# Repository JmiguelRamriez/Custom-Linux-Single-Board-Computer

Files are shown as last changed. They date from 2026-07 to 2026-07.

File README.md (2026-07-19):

# Custom Linux Single Board Computer

Open-source hardware design for a minimal **Allwinner V3s**-based Single Board Computer, designed with **KiCad 9.0**.

## Features

- **Allwinner V3s** — ARM Cortex-A7 @ 1.2 GHz with **64 MB integrated DDR2 RAM** (SiP)
- **EA3036CQB** PMIC — 3-channel regulator (1.2V / 1.8V / 3.3V) from 5V input
- **10/100 Ethernet** — integrated PHY in V3s + RJ45 with magnetics (Hanrun HR911105A)
- **USB Type-C** — power input (5V) and USB OTG
- **USB Type-A** — host port
- **microSD** card slot (Molex 104031-0811, push-push) — boot and storage
- **Debug UART** — 3-pin 2.54mm header for serial console
- **GPIO header** — 2x20 pin, Raspberry Pi-like pinout
- **CR1220** coin cell holder — RTC backup
- **Boot/reset button**

## Pinout (J6 — 40-pin GPIO Header)

```
         +3.3V  (1)  (2)  +5V
     UART2_TX  (3)  (4)  +5V
     UART2_RX  (5)  (6)  GND
     I2C0_SCL  (7)  (8)  PWM0
     I2C0_SDA  (9) (10)  PWM1
    SPI0_MISO (11) (12)  GPIO_PE2
     SPI0_CLK (13) (14)  GND
      SPI0_CS (15) (16)  GPIO_PE4
    SPI0_MOSI (17) (18)  GPIO_PE6
    GPIO_PE0  (19) (20)  GND
         +3.3V (21) (22) GPIO_PE8
    GPIO_PE1  (23) (24)  GPIO_PE10
          GND (25) (26)  GPIO_PE12
    GPIO_PE3  (27) (28)  GPIO_PE14
    GPIO_PE5  (29) (30)  GND
    GPIO_PE7  (31) (32)  GPIO_PE15
    GPIO_PE9  (33) (34)  GND
    GPIO_PE11 (35) (36)  GPIO_PE16
    GPIO_PE13 (37) (38)  GPIO_PE17
          GND (39) (40)  +1V8
```

## Gallery

### PCB Layout
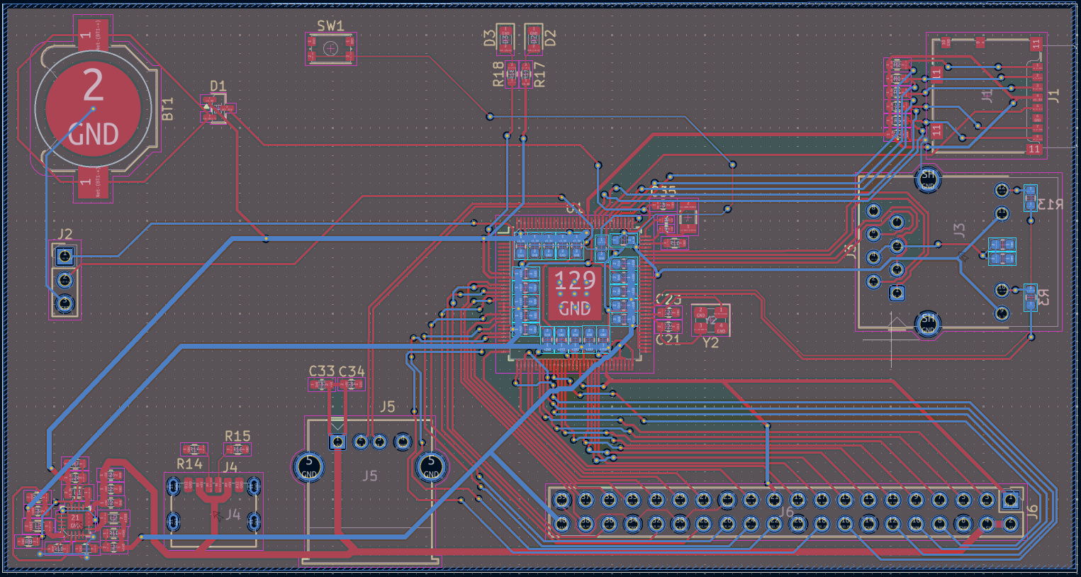
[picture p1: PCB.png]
PCB


### 3D View
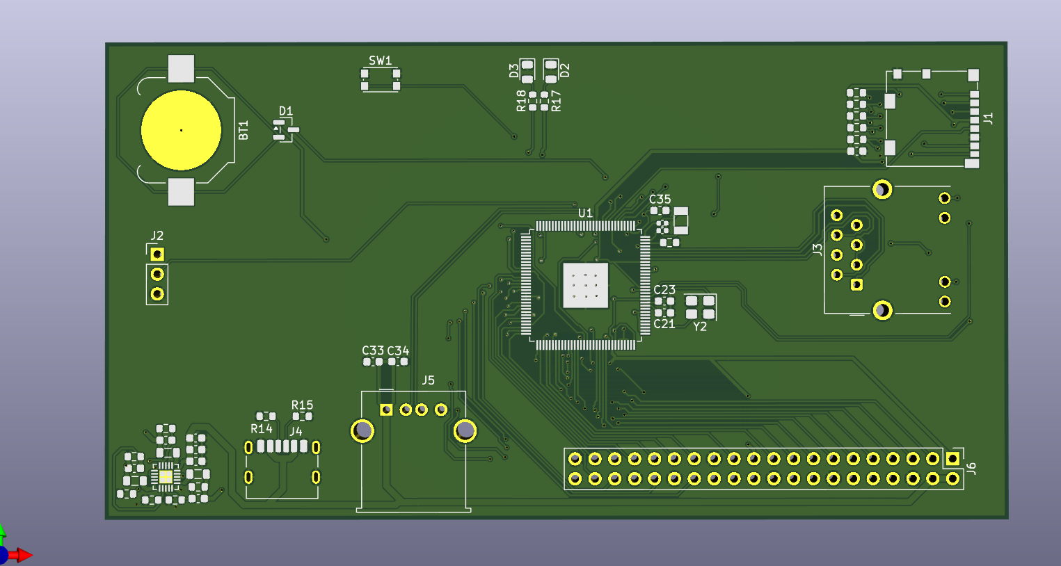
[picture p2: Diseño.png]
Diseño


### Schematic
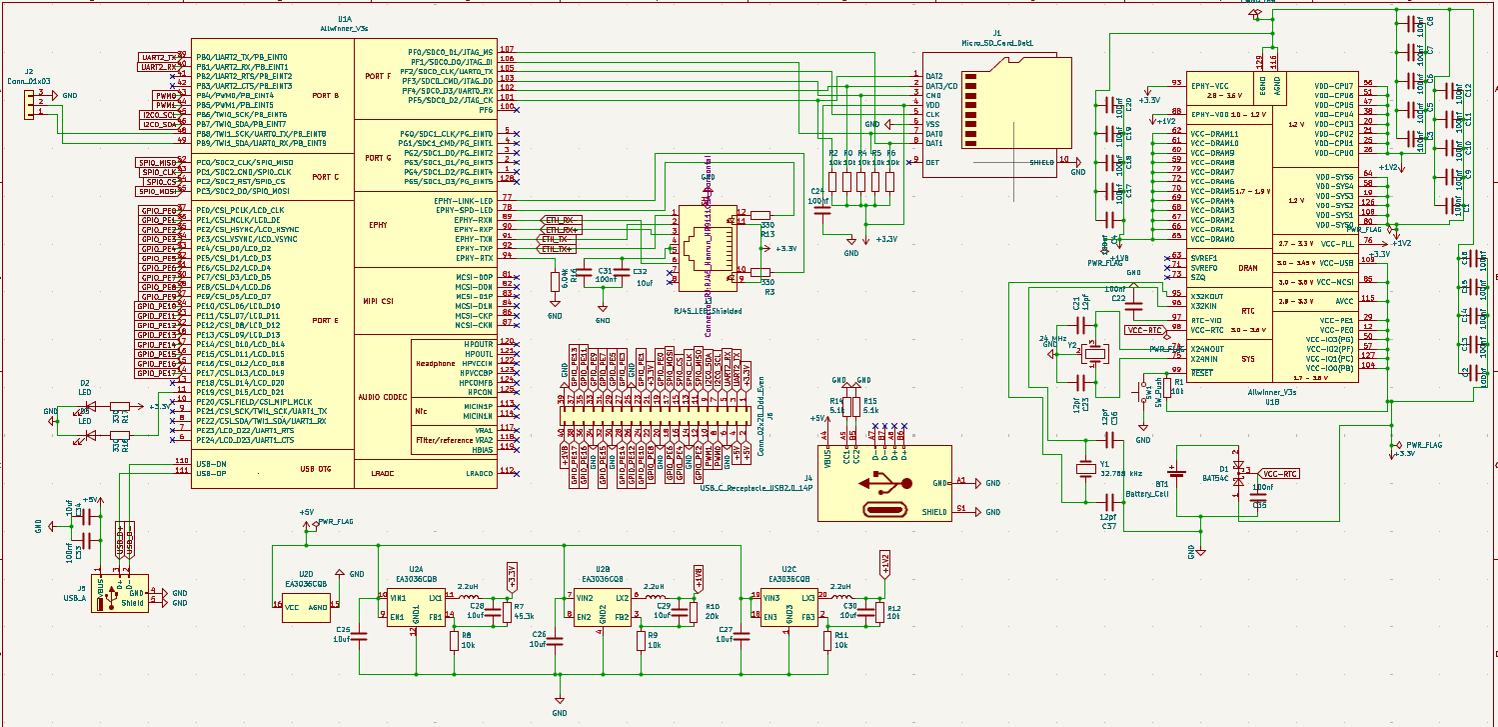
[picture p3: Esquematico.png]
Esquematico


## Board Specifications

| Parameter | Value |
|---|---|
| Layers | 4 |
| Dimensions | 115.6 × 61.2 mm |
| PCB thickness | 1.6 mm |
| Copper finish | ENIG (gold) |
| Min track width | 0.15 mm |
| Min clearance | 0.15 mm |
| Via size | 0.6 mm / 0.3 mm drill |

## Repository Contents

| File / Folder | Description |
|---|---|
| `Allwinner V3s.kicad_sch` | Schematic |
| `Allwinner V3s.kicad_pcb` | PCB layout |
| `Allwinner V3s.kicad_pro` | KiCad project file |
| `production/` | Gerbers, BOM, pick-and-place, netlist |
| `Allwinner V3s-backups/` | Design backups |

## Production Files

The `production/` folder contains everything needed for PCB fabrication and assembly:

- `Allwinner_V3s.zip` — Gerber files + NC drill
- `bom.csv` — Bill of Materials with LCSC part numbers
- `positions.csv` — Pick-and-place centroid data
- `netlist.ipc` — IPC-356 electrical test netlist

## Datasheets

| Component | Datasheet |
|---|---|
| Allwinner V3s | [V3s Datasheet V1.0](https://linux-sunxi.org/images/2/23/Allwinner_V3s_Datasheet_V1.0.pdf) |
| EA3036C (PMIC) | [EA3036C datasheet](https://www.lcsc.com/datasheet/C570857.pdf) |
| HR911105A (RJ45) | [HR911105A specification](https://www.shotech.de/Datasheet/HanRun/1811141815_HANRUN-Zhongshan-HanRun-Elec-HR911105A_C12074.pdf) |

## Status

- **DRC**: 1 warning (local footprint override, non-critical)

## License

Open hardware — use, modify, and manufacture at your own risk.

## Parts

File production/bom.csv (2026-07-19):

Designator | Footprint | Quantity | Value | LCSC Part #
BT1 | BatteryHolder_Keystone_3000_1x12mm | 1 | Battery_Cell | C238097
C1, C10, C11, C12, C13, C14, C15, C16, C17, C18, C19, C2, C20, C22, C24, C3, C31, C33, C35, C4, C5, C6, C7, C8, C9 | 0603 | 25 | 100nf | C129621
C21, C23 | 0603 | 2 | 12pf | C107034
C25, C26, C27, C28, C29, C30, C32, C34 | 0603 | 8 | 10uF | C38898
C36, C37 | 0402 | 2 | 12pf | C1547
D1 | SOT-23 | 1 | BAT54C | C2135
D2, D3 | 0805 | 2 | LED | C84256
J1 | microSD_HC_Molex_104031-0811 | 1 | Micro_SD_Card_Det1 | C585350
J2 | PinHeader_1x03_P2.54mm_Vertical | 1 | Conn_01x03 | C49257
J3 | RJ45_Hanrun_HR911105A_Horizontal | 1 | RJ45_LED_Shielded | C12074
J4 | USB_C_Receptacle_HRO_TYPE-C-31-M-17 | 1 | USB_C_Receptacle_USB2.0_14P | C165948
J5 | USB_A_Molex_67643_Horizontal | 1 | USB_A | C2765194
J6 | PinHeader_2x20_P2.54mm_Vertical | 1 | Conn_02x20_Odd_Even | C50980
L1, L2, L3 | 0805 | 3 | 2.2uH | C341781
R0, R1, R11, R12, R2, R4, R5, R6, R8, R9 | 0603 | 10 | 10k | C99198
R10 | 0603 | 1 | 20k | C105575
R13, R17, R18, R3 | 0603 | 4 | 330 | C105879
R14, R15 | 0603 | 2 | 5.1k | C3016319
R16 | 0603 | 1 | 6.04k | C25977
R7 | 0603 | 1 | 45.3k | C245971
SW1 | SW_Push_1P1T_NO_CK_KMR2 | 1 | SW_Push | C72443
U1 | eLQFP-128_14x14_Pitch0.4mm_EPAD_5.72mm | 1 | Allwinner_V3s | C2687449
U2 | QFN-20-1EP_3x3mm_P0.4mm_EP1.65x1.65mm | 1 | EA3036CQB | C570857
Y1 | Crystal_SMD_3215-2Pin_3.2x1.5mm | 1 | 32.768 kHz | C620155
Y2 | Crystal_SMD_3225-4Pin_3.2x2.5mm | 1 | 24 MHz | C70590

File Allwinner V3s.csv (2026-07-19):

Reference | Qty | Value | DNP | Exclude from BOM | Exclude from Board | Footprint | Datasheet | LCSC
BT1 | 1 | Battery_Cell |  |  |  | Battery:BatteryHolder_Keystone_3000_1x12mm | ~
C1,C2,C3,C4,C5,C6,C7,C8,C9,C10,C11,C12,C13,C14,C15,C16,C17,C18,C19,C20,C22,C24,C31,C33,C35 | 25 | 100nf |  |  |  | Capacitor_SMD:C_0603_1608Metric | ~
C21,C23 | 2 | 12pf |  |  |  | Capacitor_SMD:C_0603_1608Metric | ~
C25,C26,C27,C28,C29,C30,C32,C34 | 8 | 10uf |  |  |  | Capacitor_SMD:C_0603_1608Metric | ~
C36,C37 | 2 | 12pf |  |  |  | Capacitor_SMD:C_0402_1005Metric | ~
D1 | 1 | BAT54C |  |  |  | Package_TO_SOT_SMD:SOT-23 | http://www.diodes.com/_files/datasheets/ds11005.pdf
D2,D3 | 2 | LED |  |  |  | LED_SMD:LED_0805_2012Metric | ~
J1 | 1 | Micro_SD_Card_Det1 |  |  |  | Connector_Card:microSD_HC_Molex_104031-0811 | https://datasheet.lcsc.com/lcsc/2110151630_XKB-Connectivity-XKTF-015-N_C381082.pdf
J2 | 1 | Conn_01x03 |  |  |  | Connector_PinHeader_2.54mm:PinHeader_1x03_P2.54mm_Vertical | ~
J3 | 1 | RJ45_LED_Shielded |  |  |  | Connector_RJ:RJ45_Hanrun_HR911105A_Horizontal | ~
J4 | 1 | USB_C_Receptacle_USB2.0_14P |  |  |  | Connector_USB:USB_C_Receptacle_HRO_TYPE-C-31-M-17 | https://www.usb.org/sites/default/files/documents/usb_type-c.zip
J5 | 1 | USB_A |  |  |  | Connector_USB:USB_A_Molex_67643_Horizontal | ~
J6 | 1 | Conn_02x20_Odd_Even |  |  |  | Connector_PinHeader_2.54mm:PinHeader_2x20_P2.54mm_Vertical | ~
L1,L2,L3 | 3 | 2.2uH |  |  |  | Inductor_SMD:L_0805_2012Metric | ~
R0,R1,R2,R4,R5,R6,R8,R9,R11,R12 | 10 | 10k |  |  |  | Resistor_SMD:R_0603_1608Metric | ~
R3,R13,R17,R18 | 4 | 330 |  |  |  | Resistor_SMD:R_0603_1608Metric | ~
R7 | 1 | 45.3k |  |  |  | Resistor_SMD:R_0603_1608Metric | ~
R10 | 1 | 20k |  |  |  | Resistor_SMD:R_0603_1608Metric | ~
R14,R15 | 2 | 5.1k |  |  |  | Resistor_SMD:R_0603_1608Metric | ~
R16 | 1 | 6.04k |  |  |  | Resistor_SMD:R_0603_1608Metric | ~
SW1 | 1 | SW_Push |  |  |  | Button_Switch_SMD:SW_Push_1P1T_NO_CK_KMR2 | ~
U1 | 1 | Allwinner_V3s |  |  |  | Allwinner_SiPs:eLQFP-128_14x14_Pitch0.4mm_EPAD_5.72mm | https://linux-sunxi.org/images/2/23/Allwinner_V3s_Datasheet_V1.0.pdf | C9900008288
U2 | 1 | EA3036CQB |  |  |  | Package_DFN_QFN:QFN-20-1EP_3x3mm_P0.4mm_EP1.65x1.65mm | https://atta.szlcsc.com/upload/public/pdf/source/20200529/C570857_65255DA4FBC4C795D9FF4AFE8A3669F7.pdf
Y1 | 1 | 32.768 kHz |  |  |  | Crystal:Crystal_SMD_3215-2Pin_3.2x1.5mm | ~
Y2 | 1 | 24 MHz |  |  |  | Crystal:Crystal_SMD_3225-4Pin_3.2x2.5mm | ~

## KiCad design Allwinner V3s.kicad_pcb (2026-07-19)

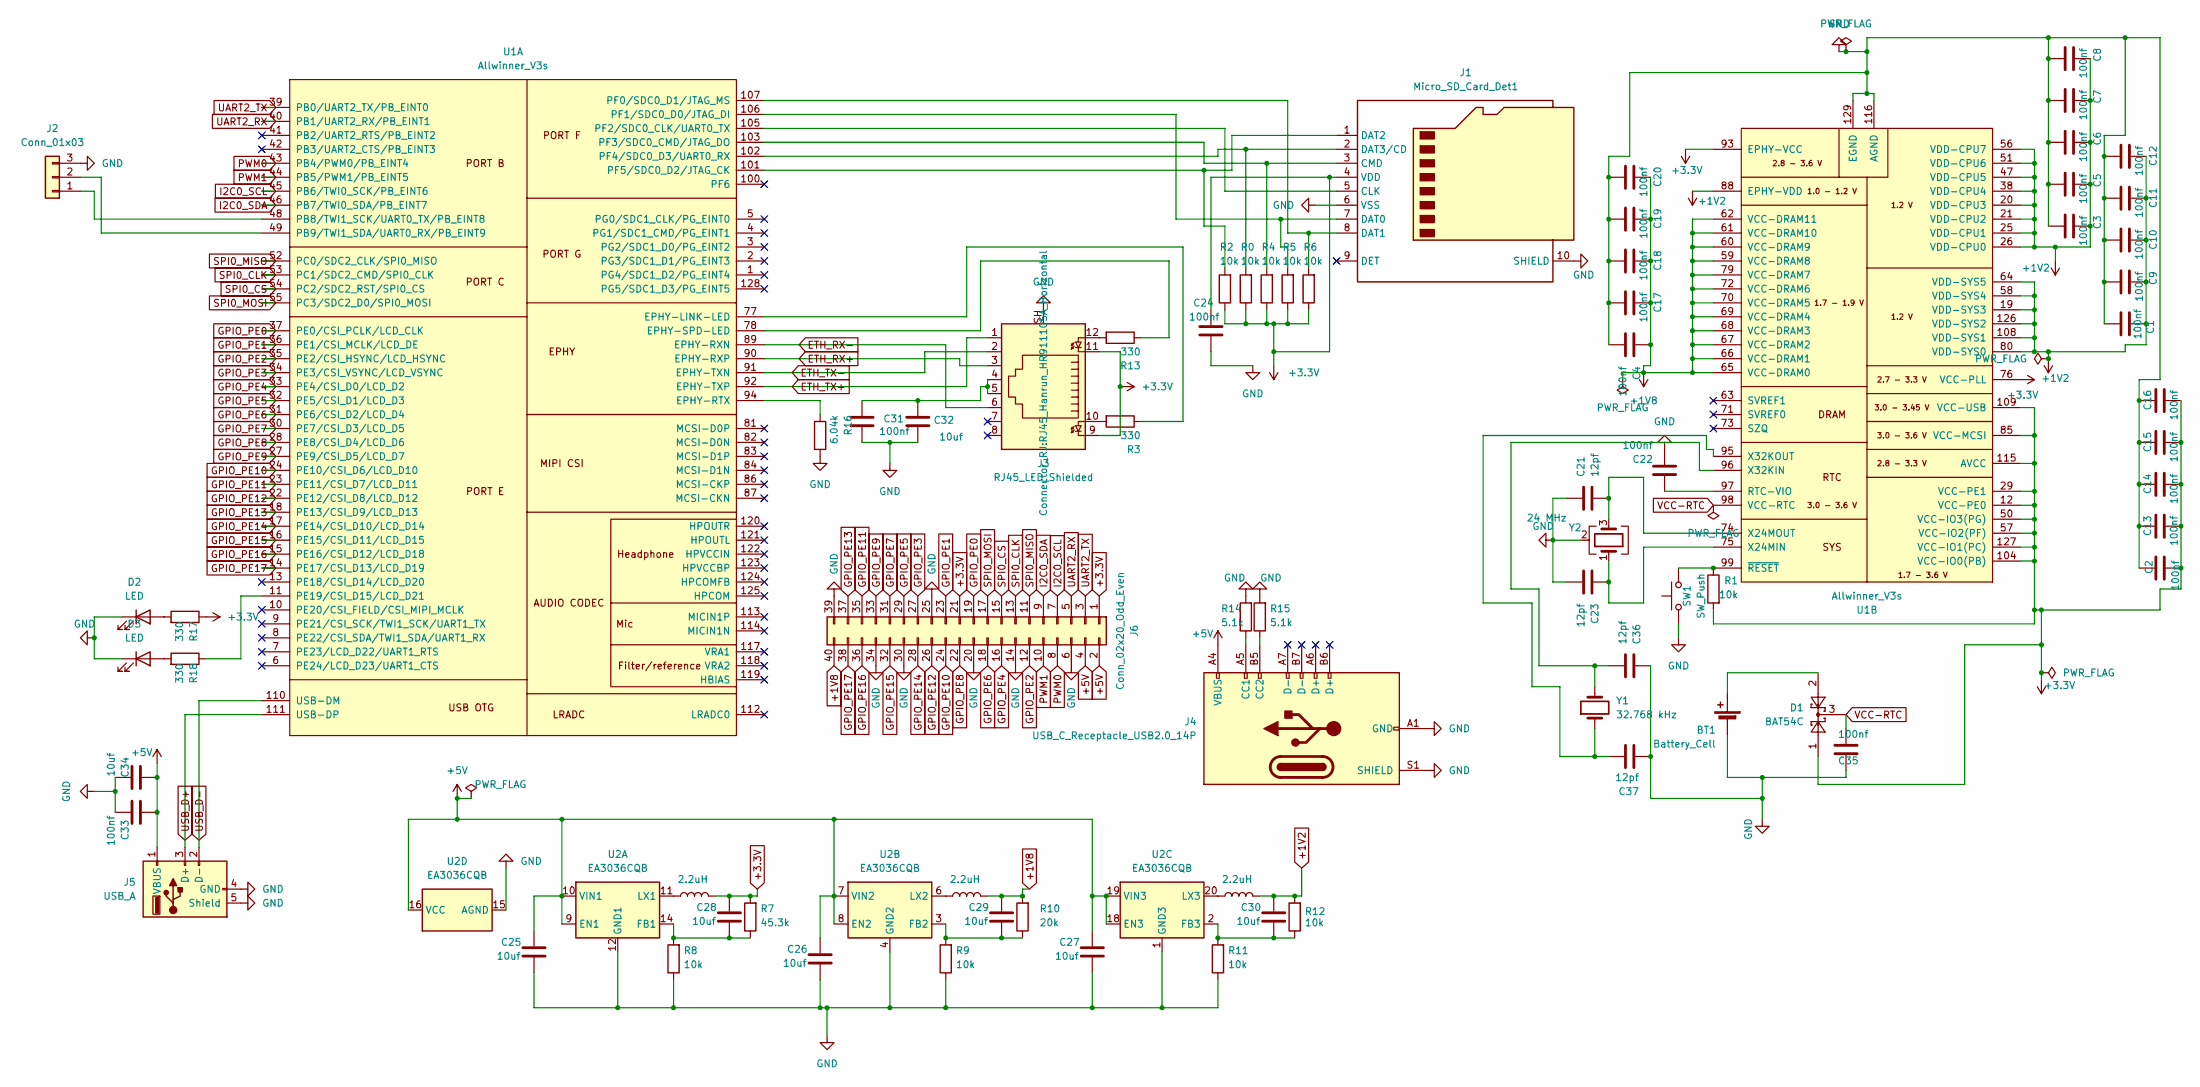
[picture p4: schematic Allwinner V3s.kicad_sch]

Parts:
BT1: Battery_Cell; BatteryHolder_Keystone_3000_1x12mm
C1, C2, C3, C4, C5, C6, C7, C8, C9, C10, C11, C12, C13, C14, C15, C16, C17, C18, C19, C20, C22, C24, C31, C33, C35: 100nf; C_0603_1608Metric
C21, C23: 12pf; C_0603_1608Metric
C25, C26, C27, C28, C29, C30, C32, C34: 10uf; C_0603_1608Metric
C36, C37: 12pf; C_0402_1005Metric
D1: BAT54C; SOT-23
D2, D3: LED; LED_0805_2012Metric
J1: Micro_SD_Card_Det1; microSD_HC_Molex_104031-0811
J2: Conn_01x03; PinHeader_1x03_P2.54mm_Vertical
J3: RJ45_LED_Shielded; RJ45_Hanrun_HR911105A_Horizontal
J4: USB_C_Receptacle_USB2.0_14P; USB_C_Receptacle_HRO_TYPE-C-31-M-17
J5: USB_A; USB_A_Molex_67643_Horizontal
J6: Conn_02x20_Odd_Even; PinHeader_2x20_P2.54mm_Vertical
L1, L2, L3: 2.2uH; L_0805_2012Metric
R0, R1, R2, R4, R5, R6, R8, R9, R11, R12: 10k; R_0603_1608Metric
R3, R13, R17, R18: 330; R_0603_1608Metric
R7: 45.3k; R_0603_1608Metric
R10: 20k; R_0603_1608Metric
R14, R15: 5.1k; R_0603_1608Metric
R16: 6.04k; R_0603_1608Metric
SW1: SW_Push; SW_Push_1P1T_NO_CK_KMR2
U1: Allwinner_V3s; eLQFP-128_14x14_Pitch0.4mm_EPAD_5.72mm; LCSC C9900008288
U2: EA3036CQB; QFN-20-1EP_3x3mm_P0.4mm_EP1.65x1.65mm
Y1: 32.768 kHz; Crystal_SMD_3215-2Pin_3.2x1.5mm
Y2: 24 MHz; Crystal_SMD_3225-4Pin_3.2x2.5mm

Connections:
+1V2: C1.1, C3.1, C5.1, C6.1, C7.1, C8.1, C9.1, C10.1, C11.1, C12.1, C30.1, L3.2, R12.2, U1.19 (VDD-SYS3), U1.20 (VDD-CPU3), U1.21 (VDD-CPU2), U1.25 (VDD-CPU1), U1.26 (VDD-CPU0), U1.38 (VDD-CPU4), U1.47 (VDD-CPU5), U1.51 (VDD-CPU6), U1.56 (VDD-CPU7), U1.58 (VDD-SYS4), U1.64 (VDD-SYS5), U1.80 (VDD-SYS0), U1.88 (EPHY-VDD), U1.108 (VDD-SYS1), U1.126 (VDD-SYS2)
+1V8: C4.1, C17.1, C18.1, C19.1, C20.1, C29.1, J6.40, L2.2, R10.2, U1.59 (VCC-DRAM8), U1.60 (VCC-DRAM9), U1.61 (VCC-DRAM10), U1.62 (VCC-DRAM11), U1.65 (VCC-DRAM0), U1.66 (VCC-DRAM1), U1.67 (VCC-DRAM2), U1.68 (VCC-DRAM3), U1.69 (VCC-DRAM4), U1.70 (VCC-DRAM5), U1.72 (VCC-DRAM6), U1.79 (VCC-DRAM7)
+3.3V: C2.1, C13.1, C14.1, C15.1, C16.1, C24.1, C28.1, D1.1, J1.4 (VDD), J3.9, J3.11, J6.1, J6.21, L1.2, R0.1, R1.2, R2.1, R4.1, R5.1, R6.1, R7.2, R17.1, U1.12 (VCC-PE0), U1.29 (VCC-PE1), U1.50 (VCC-IO3(PG)), U1.57 (VCC-IO2(PF)), U1.76 (VCC-PLL), U1.85 (VCC-MCSI), U1.93 (EPHY-VCC), U1.104 (VCC-IO0(PB)), U1.109 (VCC-USB), U1.115 (AVCC), U1.127 (VCC-IO1(PC))
+5V: C25.1, C26.1, C27.1, C33.2, C34.2, J4.A4 (VBUS), J4.A9 (VBUS), J4.B4 (VBUS), J4.B9 (VBUS), J5.1 (VBUS), J6.2, J6.4, U2.7 (VIN2), U2.8 (EN2), U2.9 (EN1), U2.10 (VIN1), U2.16 (VCC), U2.18 (EN3), U2.19 (VIN3)
ETH_RX+: J3.3, U1.90 (EPHY-RXP)
ETH_RX-: J3.6, U1.89 (EPHY-RXN)
ETH_TX+: J3.1, U1.92 (EPHY-TXP)
ETH_TX-: J3.2, U1.91 (EPHY-TXN)
GND: BT1.2 (-), C1.2, C2.2, C3.2, C4.2, C5.2, C6.2, C7.2, C8.2, C9.2, C10.2, C11.2, C12.2, C13.2, C14.2, C15.2, C16.2, C17.2, C18.2, C19.2, C20.2, C21.1, C22.2, C23.2, C24.2, C25.2, C26.2, C27.2, C31.1, C32.1, C33.1, C34.1, C35.2, C36.1, C37.2, D2.1 (K), D3.1 (K), J1.6 (VSS), J1.10 (SHIELD), J2.3, J3.SH, J4.A1 (GND), J4.A12 (GND), J4.B1 (GND), J4.B12 (GND), J4.S1 (SHIELD), J5.4 (GND), J5.5 (Shield), J6.6, J6.14, J6.20, J6.25, J6.30, J6.34, J6.39, R8.1, R9.1, R11.1, R14.2, R15.2, R16.2, SW1.1, U1.116 (AGND), U1.129 (EGND), U2.1 (GND3), U2.4 (GND2), U2.5 (GND2), U2.12 (GND1), U2.13 (GND1), U2.15 (AGND), U2.17 (AGND), U2.21 (AGND), Y2.2 (G), Y2.4 (G)
GPIO_PE0: J6.19, U1.37 (PE0/CSI_PCLK/LCD_CLK)
GPIO_PE1: J6.23, U1.36 (PE1/CSI_MCLK/LCD_DE)
GPIO_PE2: J6.12, U1.35 (PE2/CSI_HSYNC/LCD_HSYNC)
GPIO_PE3: J6.27, U1.34 (PE3/CSI_VSYNC/LCD_VSYNC)
GPIO_PE4: J6.16, U1.33 (PE4/CSI_D0/LCD_D2)
GPIO_PE5: J6.29, U1.32 (PE5/CSI_D1/LCD_D3)
GPIO_PE6: J6.18, U1.31 (PE6/CSI_D2/LCD_D4)
GPIO_PE7: J6.31, U1.30 (PE7/CSI_D3/LCD_D5)
GPIO_PE8: J6.22, U1.28 (PE8/CSI_D4/LCD_D6)
GPIO_PE9: J6.33, U1.27 (PE9/CSI_D5/LCD_D7)
GPIO_PE10: J6.24, U1.24 (PE10/CSI_D6/LCD_D10)
GPIO_PE11: J6.35, U1.23 (PE11/CSI_D7/LCD_D11)
GPIO_PE12: J6.26, U1.22 (PE12/CSI_D8/LCD_D12)
GPIO_PE13: J6.37, U1.18 (PE13/CSI_D9/LCD_D13)
GPIO_PE14: J6.28, U1.17 (PE14/CSI_D10/LCD_D14)
GPIO_PE15: J6.32, U1.16 (PE15/CSI_D11/LCD_D15)
GPIO_PE16: J6.36, U1.15 (PE16/CSI_D12/LCD_D18)
GPIO_PE17: J6.38, U1.14 (PE17/CSI_D13/LCD_D19)
I2C0_SCL: J6.7, U1.45 (PB6/TWI0_SCK/PB_EINT6)
I2C0_SDA: J6.9, U1.46 (PB7/TWI0_SDA/PB_EINT7)
unnamed: BT1.1 (+), D1.2
unnamed: C31.2, C32.2, J3.4, J3.5
unnamed: D2.2 (A), R17.2
unnamed: D3.2 (A), R18.2
unnamed: J1.5 (CLK), U1.105 (PF2/SDC0_CLK/UART0_TX)
unnamed: J1.3 (CMD), R4.2, U1.103 (PF3/SDC0_CMD/JTAG_DO)
unnamed: J1.7 (DAT0), R5.2, U1.106 (PF1/SDC0_D0/JTAG_DI)
unnamed: J1.8 (DAT1), R6.2, U1.107 (PF0/SDC0_D1/JTAG_MS)
unnamed: J1.1 (DAT2), R2.2, U1.101 (PF5/SDC0_D2/JTAG_CK)
unnamed: J1.2 (DAT3/CD), R0.2, U1.102 (PF4/SDC0_D3/UART0_RX)
unnamed: J2.1, U1.48 (PB8/TWI1_SCK/UART0_TX/PB_EINT8)
unnamed: J2.2, U1.49 (PB9/TWI1_SDA/UART0_RX/PB_EINT9)
unnamed: J3.10, R3.2
unnamed: J3.12, R13.2
unnamed: J4.A5 (CC1), R14.1
unnamed: J4.B5 (CC2), R15.1
unnamed: R3.1, U1.77 (EPHY-LINK-LED)
unnamed: R16.1, U1.94 (EPHY-RTX)
unnamed: R13.1, U1.78 (EPHY-SPD-LED)
unnamed: R18.1, U1.11 (PE19/CSI_D15/LCD_D21)
unnamed: C22.1, U1.97 (RTC-VIO)
unnamed: C23.1, U1.75 (X24MIN), Y2.1
unnamed: C21.2, U1.74 (X24MOUT), Y2.3
unnamed: C36.2, U1.96 (X32KIN), Y1.2
unnamed: C37.1, U1.95 (X32KOUT), Y1.1
unnamed: R1.1, SW1.2, U1.99 (~RESET)
unnamed: C28.2, R7.1, R8.2, U2.14 (FB1)
unnamed: L1.1, U2.11 (LX1)
unnamed: C29.2, R9.2, R10.1, U2.3 (FB2)
unnamed: L2.1, U2.6 (LX2)
unnamed: C30.2, R11.2, R12.1, U2.2 (FB3)
unnamed: L3.1, U2.20 (LX3)
PWM0: J6.8, U1.43 (PB4/PWM0/PB_EINT4)
PWM1: J6.10, U1.44 (PB5/PWM1/PB_EINT5)
SPI0_CLK: J6.13, U1.53 (PC1/SDC2_CMD/SPI0_CLK)
SPI0_CS: J6.15, U1.54 (PC2/SDC2_RST/SPI0_CS)
SPI0_MISO: J6.11, U1.52 (PC0/SDC2_CLK/SPI0_MISO)
SPI0_MOSI: J6.17, U1.55 (PC3/SDC2_D0/SPI0_MOSI)
UART2_RX: J6.5, U1.40 (PB1/UART2_RX/PB_EINT1)
UART2_TX: J6.3, U1.39 (PB0/UART2_TX/PB_EINT0)
USB_D+: J5.3 (D+), U1.111 (USB-DP)
USB_D-: J5.2 (D-), U1.110 (USB-DM)
VCC-RTC: C35.1, D1.3, U1.98 (VCC-RTC)

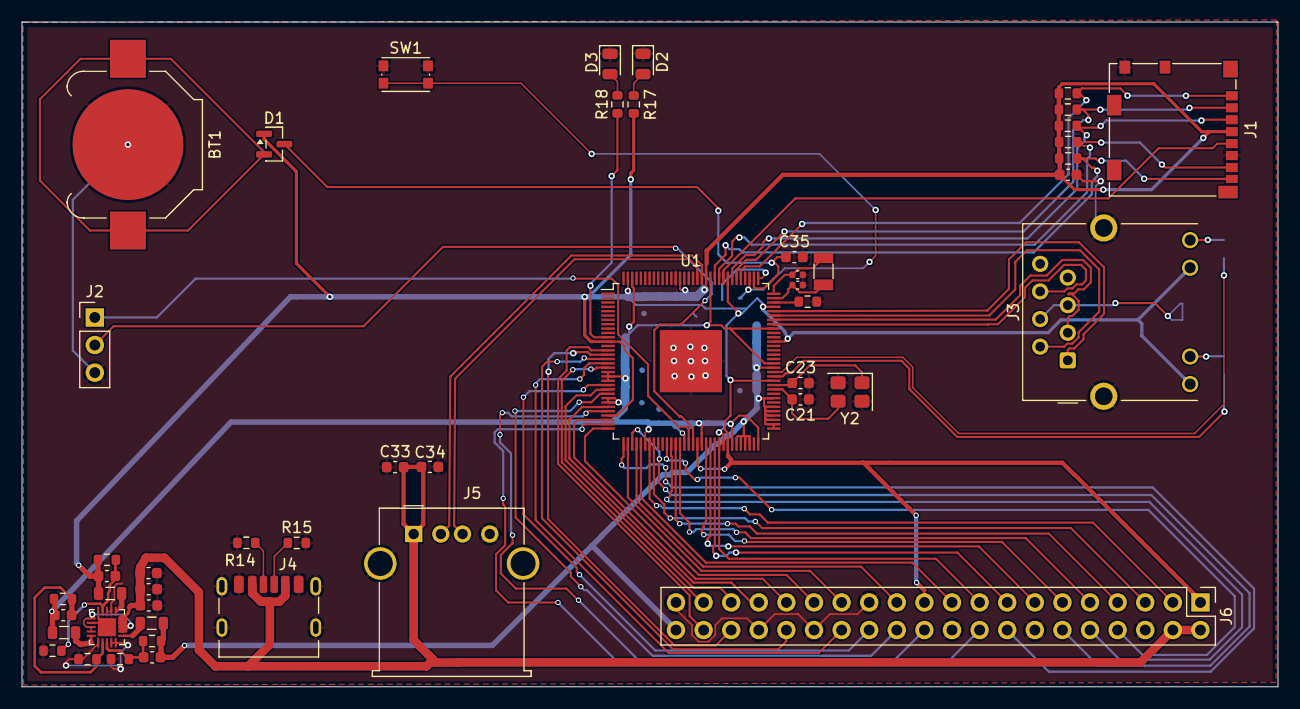
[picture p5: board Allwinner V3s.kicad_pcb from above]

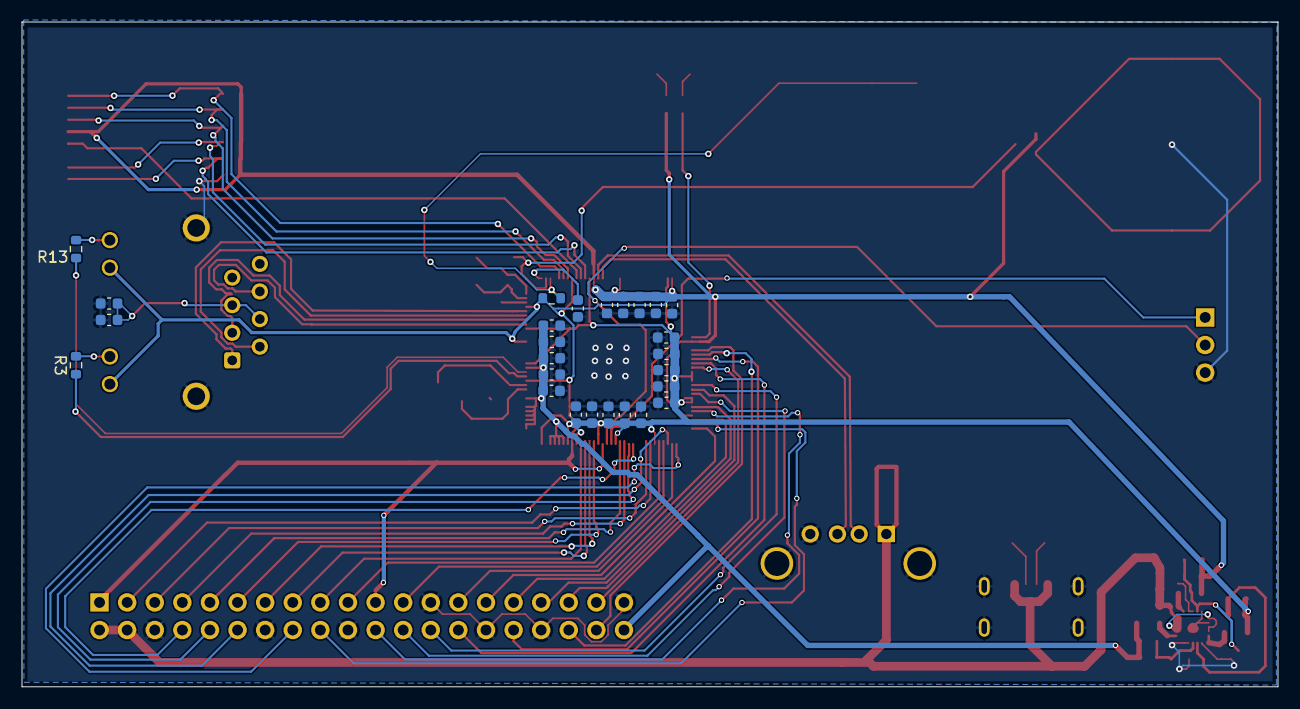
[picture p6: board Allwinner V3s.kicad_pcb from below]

Board: 4 copper layers, 115.6 x 61.2 mm, 74 parts (26 on the bottom side), 72 nets.
